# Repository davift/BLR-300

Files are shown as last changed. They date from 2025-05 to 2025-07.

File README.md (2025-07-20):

# BLR-300

Key Card Addon: Binary LED Reader - 300 (BLR-300)

This write-up walks through the process of solving the hardware challenge in the NSEC 2025 CTF.

**NOTE:** This is a beginner-friendly challenge that mostly requires investigating traces and understanding the direction of current flow.

The official source code released by NSEC for the Badge and Dock is available at [NSEC-Badge](https://github.com/nsec/nsec-badge/)

## Overview

The objectives of this challenge are:

- First, fix the existing issues on the provided board so it will properly blink the LEDs.
- Second, decipher the message output by the LEDs to obtain the flag.

**Note:** The board is attached to the badge, which is then connected to a dock available next to the soldering village to output the ciphered code. The badge by itself does not light up anything. The secret message resides on the dock. I saw one participant sniffing the pins on the badge to capture the ciphered message without fixing the board. While extremely clever, the board will reveal necessary facts about some of the pins.

Overview

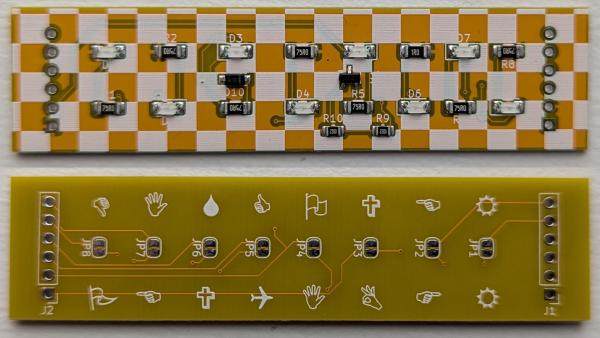
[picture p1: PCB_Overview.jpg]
Overview of the Board


I decided to write this guide because, after talking with participants of the competition, most were not familiar enough with the challenge to give it a try.

## Beforehand

A PDF was provided: [BLR-300-Reference-manual.pdf](https://github.com/davift/BLR-300/blob/main/BLR-300-Reference-manual.pdf), which is a guide/datasheet and also provides clues about what to look for.

Read it carefully before making any modifications to the board. Make notes of the tips and clues in that document to explore.

## Pinout and Schematics

Start by drawing a schematic of the circuit. KiCad (a free and open-source application) might help, but just pen and paper can get the job done.

**NOTE:** There is a checkered pattern printed on the board to make following the traces and reverse engineering more difficult.

Datasheet Notes Revealed

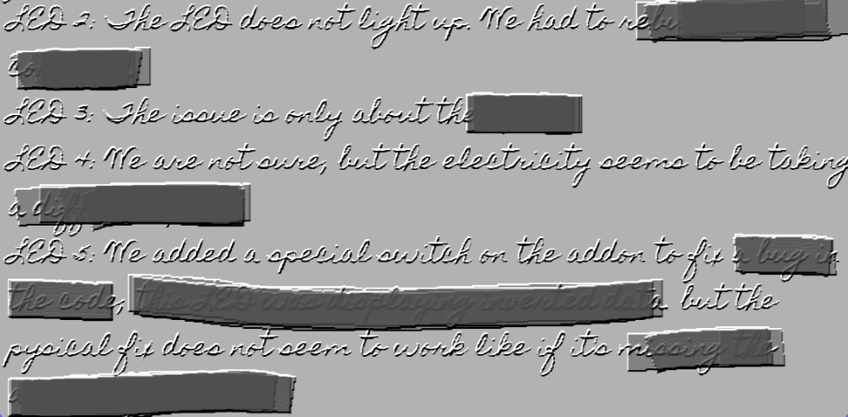
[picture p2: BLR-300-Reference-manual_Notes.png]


Datasheet Pinout Table

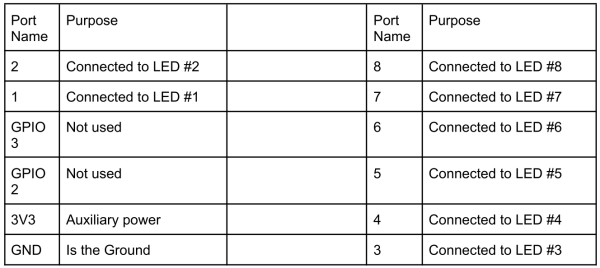
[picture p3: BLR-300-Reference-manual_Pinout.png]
Pinout Table


Pinout (see high resolution here: [PCB Front](https://github.com/davift/BLR-300/blob/main/PCB_Front_Big.jpg) and [PCB Back](https://github.com/davift/BLR-300/blob/main/PCB_Back_Big.jpg)).

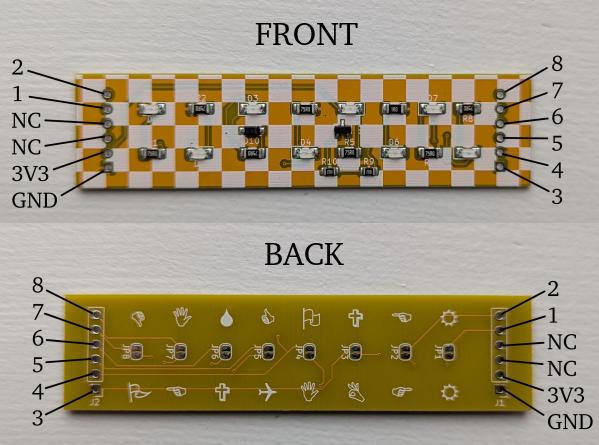
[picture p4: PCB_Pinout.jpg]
Board Pinout


Schematics (see high resolution here: [PCB Schematics](https://github.com/davift/BLR-300/blob/main/PCB_Schematics_Big.png)).

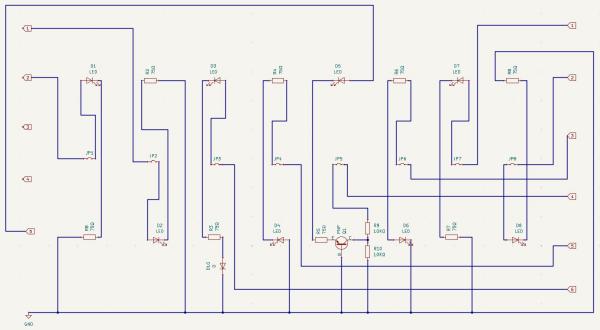
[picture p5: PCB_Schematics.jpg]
Schematics


Basic steps:

- Visually inspect the board and all its features/components.
  - Identify the 8 LEDs.
  - Identify the resistors connected to each LED.
  - Identify any other components and what they relate to.
  - Use a flashlight to shine through the board. This allows you to see behind the printed obfuscation pattern.

See through paint with backlight (see high resolution [here](https://github.com/davift/BLR-300/blob/main/PCB_Backlight_Big.jpg)).

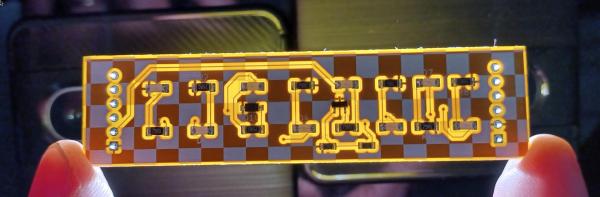
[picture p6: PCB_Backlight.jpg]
PCB Backlight


- Use a multimeter to:
  - Test continuity between all 12 pins of the board (some might be shorted).
  - Follow each trace on the board to test for connectivity (some might be broken).
  - Test LEDs and other diodes for polarity (some might be inverted).
  - Test the resistors (some might not be appropriately sized).
  - Cross-reference the pinout table from the datasheet with the LEDs (some might be swapped).

By performing the inspections above, most, if not all, issues can be identified.

## Issues Found

### LED 1

Testing the LED orientation with a multimeter will reveal it is incorrect.

It is necessary to desolder and solder it back. This process frequently destroys the LED because of the heat. If necessary, ask for another RED SMD LED from one of the organizers.

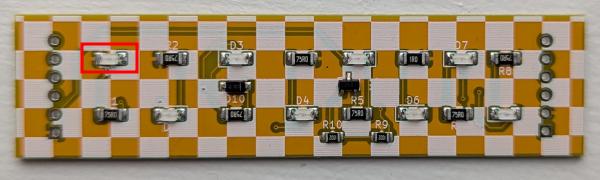
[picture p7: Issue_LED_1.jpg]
Issues on LED 1


### LED 2

There is no connectivity between the header pin and the LED. A visual inspection may not reveal this issue because of the printed obfuscation pattern. Use the multimeter to check continuity.

It is easy to fix with an external wire to make the route.

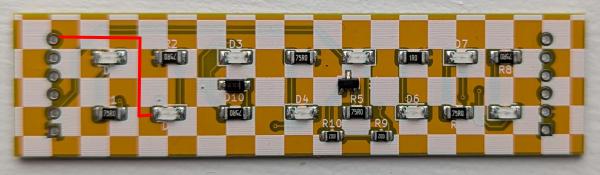
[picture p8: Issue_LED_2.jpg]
Issues on LED 2


### LED 3

Visually, it is not possible to see the polarity of the diode in series with this LED. Use the multimeter to check continuity through the components.

The highlighted diode is not necessary and can be bypassed or have its orientation inverted.

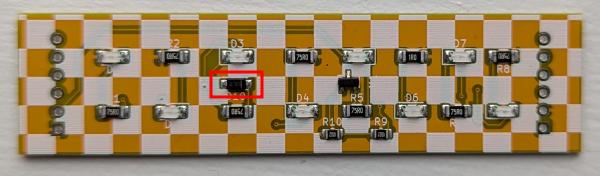
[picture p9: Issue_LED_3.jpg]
Issues on LED 3


### LED 4

This LED appears to malfunction, but the circuit is shorted in multiple locations.

On the back, there is an odd trace to a hole right next to ground on the other side. Cut it with a utility knife or any sharp metal tool.

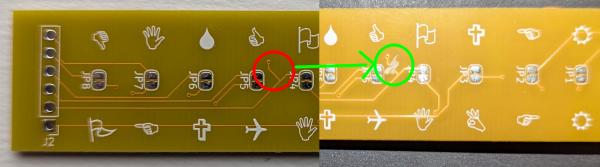
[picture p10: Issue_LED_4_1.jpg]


On the front, there are two other shorts right at the header pin. If the header is already soldered, it might be a bit trickier to cut them.

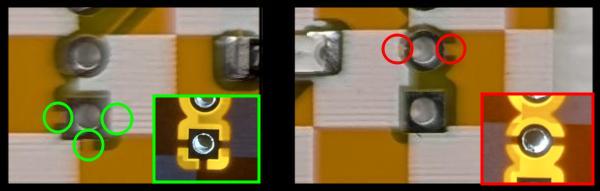
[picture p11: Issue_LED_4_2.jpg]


### LED 5

This was the trickiest issue in this challenge because it takes time to analyze what this extra circuit is doing: a PNP transistor with two 10K ohm resistors.

There is no issue with the transistor, after all. But the circuit that connects pin 3V3 to the LED does not work and needs to be re-routed.

I did not find any purpose for resistors 9 and 10, so I shorted 9 and removed 10. Maybe it was not necessary.

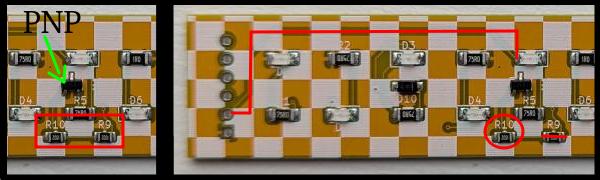
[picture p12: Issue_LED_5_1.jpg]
Issues on LED 5


### LED 6

The manual has the note: "The LED has a tendency to die easily if lighted up for a long time." This comment implies that the resistor that protects the LED is too low or nonexistent.

A visual inspection might reveal that, while all the other LEDs have a 75-ohm resistor, this LED has a 1-ohm resistor. Just ask the challenge organizers for a replacement resistor.

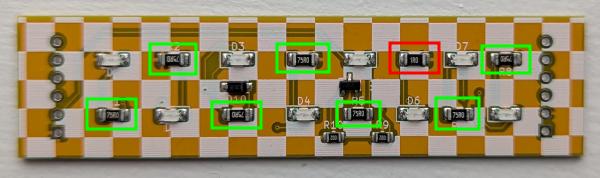
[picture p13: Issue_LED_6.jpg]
Issues on LED 6


### LED 7 and LED 8

These two work out of the box, which makes it easy to overlook that they are swapped. This issue will cause the encoded/ciphered message to be incorrect.

Open the bridges on the back and reroute the circuits, swapping the pins using any piece of wire.

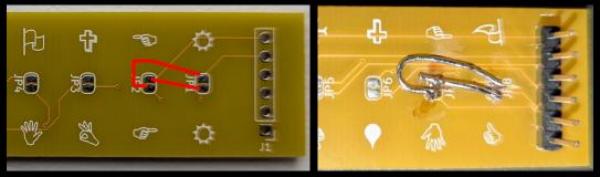
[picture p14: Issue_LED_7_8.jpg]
Issues on LED 7 and 8


## Issues Fixed

This is how the changes look after all fixes have been applied.

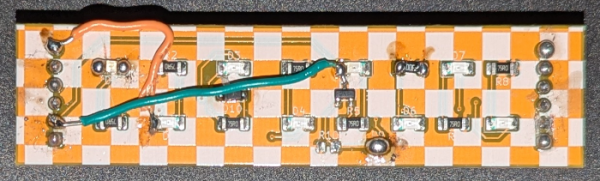
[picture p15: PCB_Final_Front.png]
PCB Final Front


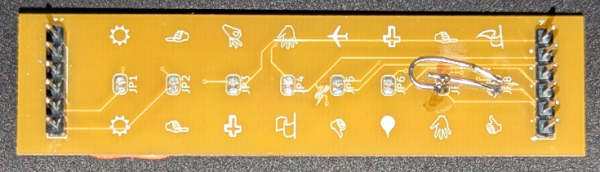
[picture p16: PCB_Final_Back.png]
PCB Final Back


At this point, the PCB can be connected to the badge and attached to the dock provided by the organizers of the challenge to capture the ciphered code.

## Encoded system

[![Message Captured]](https://www.youtube.com/shorts/3g_Ai0capvw)

From the video we got the following byte sequence.

Note: LEDs 7 and 8 were still inverted at the time of the recording.

```
00001010
00100111
11011000
11110101
00001010
11110101
00001010
10001111
00001101
00000110
10000111
00010001
00101111
00011100
00110010
10110110
10100110
10010110
00011100
10110010
00010101
00001110
00111111
00110010
10010110
00110010
10100110
00000101
00001110
00011111
10011101
10110010
10110110
00010010
11110101
00001010
11110101
00001010
11011010
11011000
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
...
```

The comment in the datasheet "Expected Communication Pattern on a non-rewired addon: 11110101 00001010 ..." indicates the begining of the message. We have a match!

There are two keys described in the datasheet as CLIENT DEFAULT KEY and SCRAMBLED KEY.

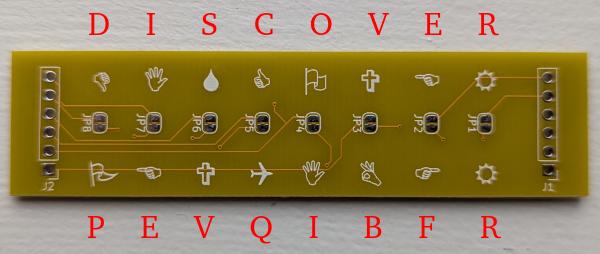
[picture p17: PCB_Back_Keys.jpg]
PCB Final Back


There is an old Windows font called Wingdings that contains the same symbols printed on the back of the board. Those keys were decoded with the chart below.

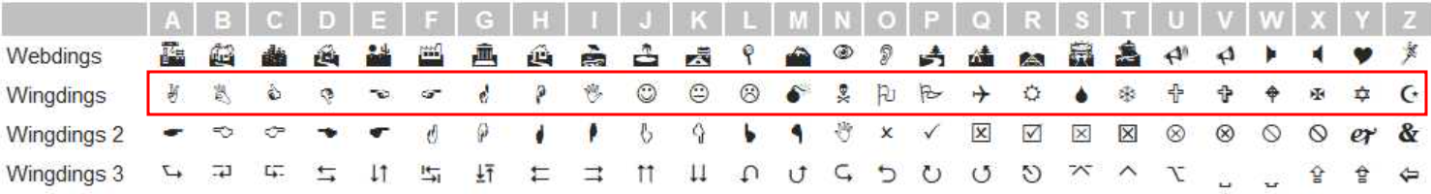
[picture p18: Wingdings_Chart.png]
Wingdings Chart


(to be continued)

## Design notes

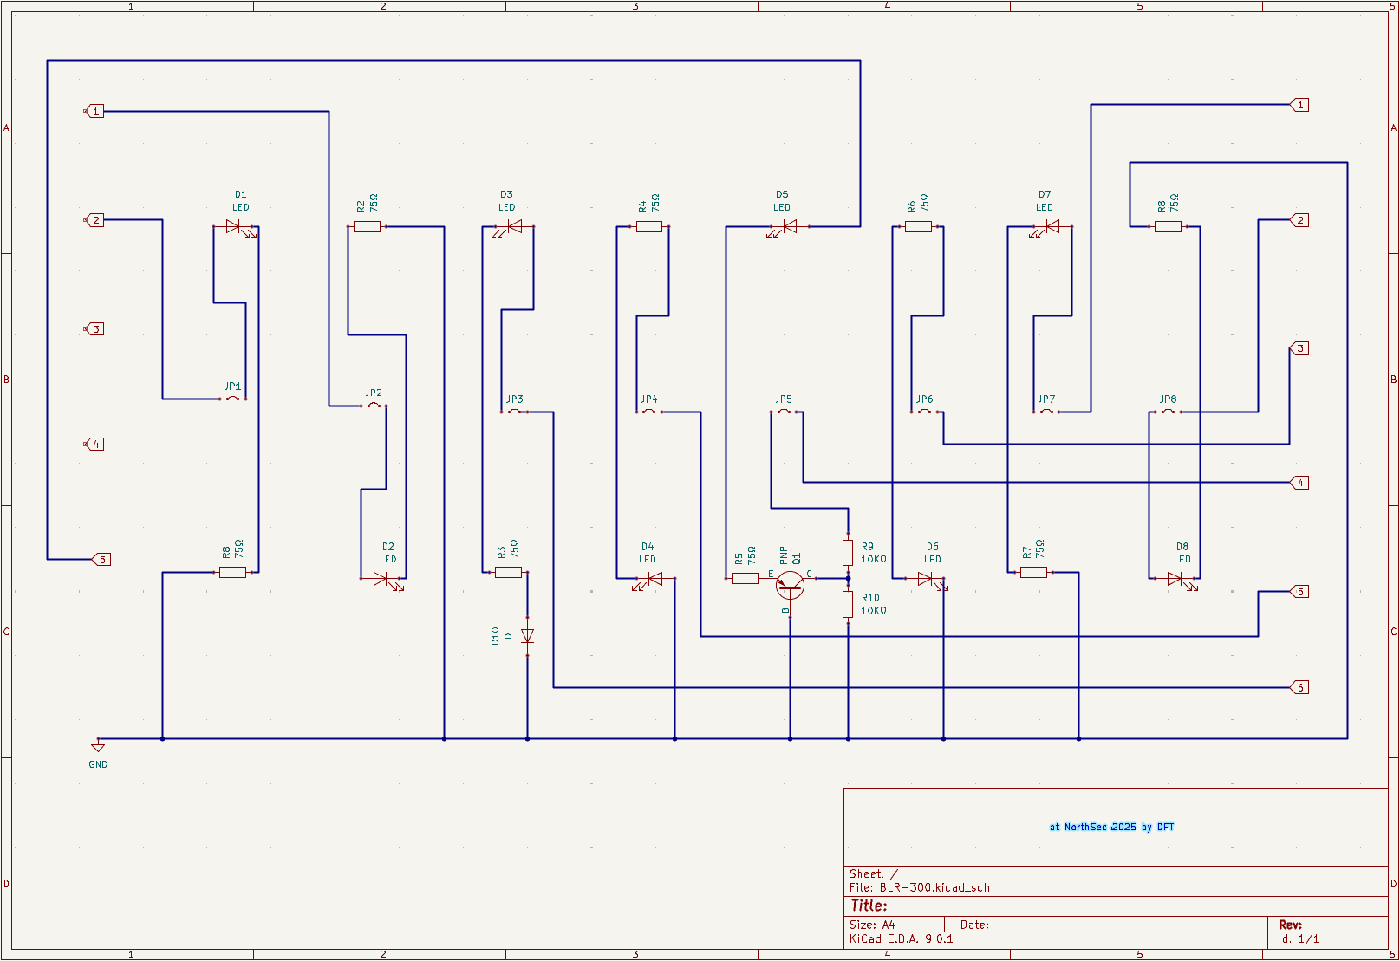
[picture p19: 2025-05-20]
PCB_Schematics_Big.png

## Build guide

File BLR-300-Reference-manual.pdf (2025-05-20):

# Ke Car Addo: Binar LED Reader - 300 (BLR-300)

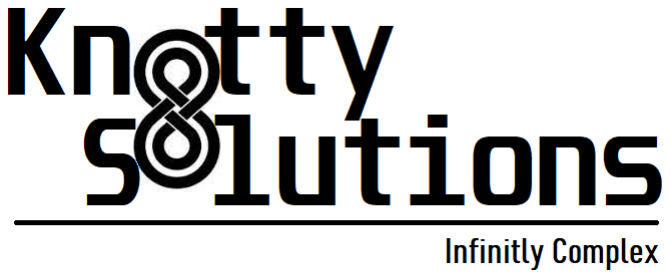
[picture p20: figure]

## Reference Manual

Beta version 0.7.9 (Not for public distribution)
FLAG-ITS-RTFM-TIME!!

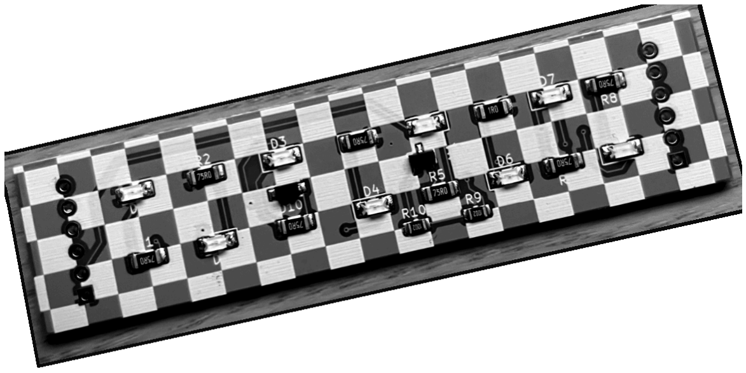
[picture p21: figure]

# OVERVIEW

AT Knotty Solutions we create complex products. We firmly believe that by using more complex ways to build our solutions we improve the security of our products. This add-on represents the hard work we have put in order to reach a nice peak in security.

For our main product; the key card reader system, we created a special Addon, named the BLR-300, that allows our customers to access more information when interacting with the card reader. Through that addon, we are using an advanced communication system based on 8 LEDs designed to communicate with binary. This makes the debugging process much more efficient when using the card reader system.

Dev notes (TODO remove for final release):

# ADDON DISTRIBUTION AND INSTALLATION

Since the BLR-300 is not designed for public usage, and should not be distributed to the public, in order to reduce the cost, the initial package comes in separate pieces. You will need to assemble your own addon.

Note: Make sure you carefully assemble connection legs; they need to have a correct solder and correctly aligned for an easier insertion.

Note: For the installation of the addon on the key card, make sure you use this orientation:

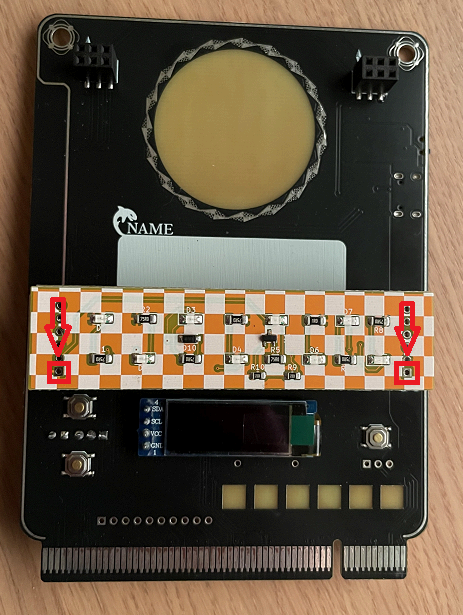
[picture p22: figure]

Dev notes (TODO remove for final release):

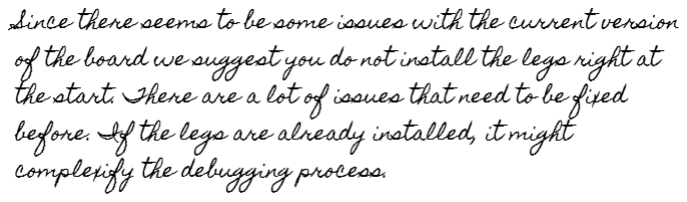
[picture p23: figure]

# ADDON MAINTENANCE

If you are required to do some maintenance on the BLR-300, know this will void your warranty. This means in order to keep our technology super secret, we do not provide in-depth information on the construction of the add-on; so no BOM, or schematic. Which means you will have to re-order the add-on from us via your sales representative.

To further repel anyone that would even try to do reverse engineering on our product we even made the reading of the board harder with a special pattern printed on it to protect the BLR-300 from reverse engineering!

Dev notes (TODO remove for final release):

# Architecture Overview

The addon uses 8 LEDs to communicate. To have an efficient communication protocol, each LEDs is connected to its own port. Here is a small Communication PORT reference grid.

Port Name | Purpose | Port Name | Purpose
2 | Connected to LED #2 | 8 | Connected to LED #8
1 | Connected to LED #1 | 7 | Connected to LED #7
GPIO 3 | Not used | 6 | Connected to LED #6
GPIO 2 | Not used | 5 | Connected to LED #5
3V3 | Auxiliary power | 4 | Connected to LED #4
GND | Is the Ground | 3 | Connected to LED #3

Dev notes (TODO remove for final release):

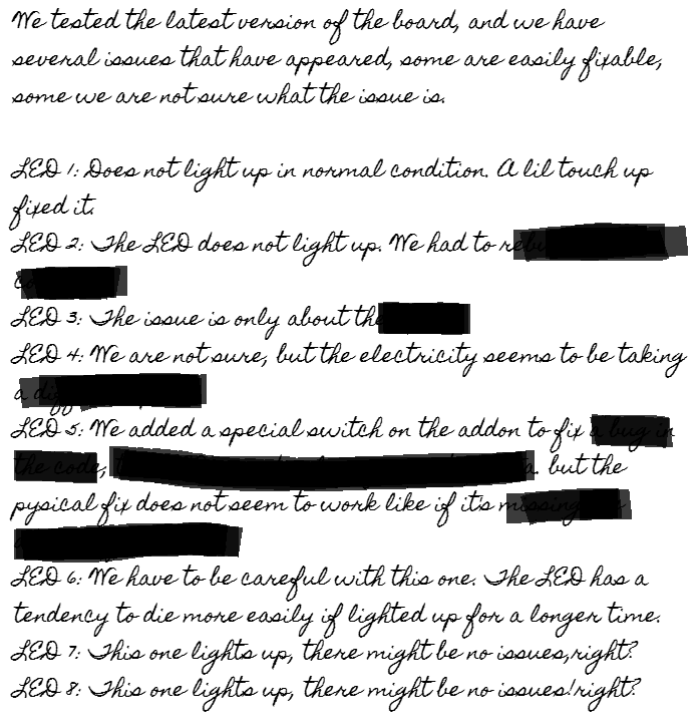
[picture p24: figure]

# Communication Protocol

The Addon will communicate with the LEDs in a specific pattern. It will output messages in a binary format using all 8 LEDs. So it's very important that all the LEDs are functional. In order to make sure you get all the messages we have a special communication header and footer that indicates you everything is functional like it should.

After connecting the augmented badge with an add-on to a station, the LEDs will start displaying data.

IF the addon has been rewired to apply the scrambled key correctly, the following will be displayed:
Communication Header Pattern:

All LEDs ON
All LEDs OFF
All LEDs ON
All LEDs OFF
Bottom LEDS ON Only
Top LEDS ON Only
All LEDs ON
All LEDs OFF
All LEDs ON
All LEDs OFF

Communication Data:

Normal Binary Data

Communication Footer Pattern:

All LEDs ON
All LEDs OFF
All LEDs ON
All LEDs OFF
Top LEDS ON Only
Bottom LEDS ON Only
All LEDs ON
All LEDs OFF
All LEDs ON
All LEDs OFF

Dev notes (TODO remove for final release):

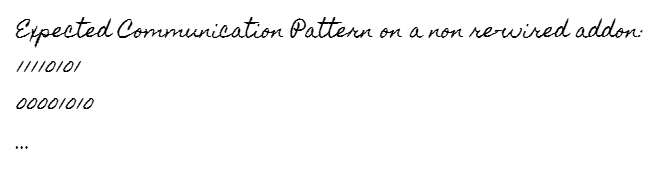
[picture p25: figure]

# Encoded system

To further improve the security of our addon, we personalize the addon connection for each client. We create a unique key that links the addon to the stations provided so they don't work at our other client’s stations. In other words the stations provided use the encoded scrambled key and the Addon must be rewired to match your stations.

By default the addon is using the default wiring to use the default non-scrambled key.

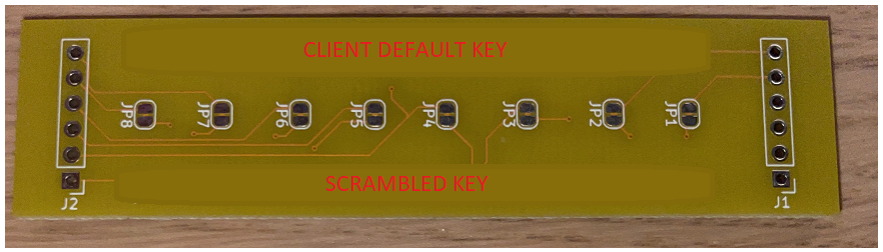
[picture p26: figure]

To make the addon work with your stations, first you must cut the default connection and then rewire the connection to match the scrambled key.

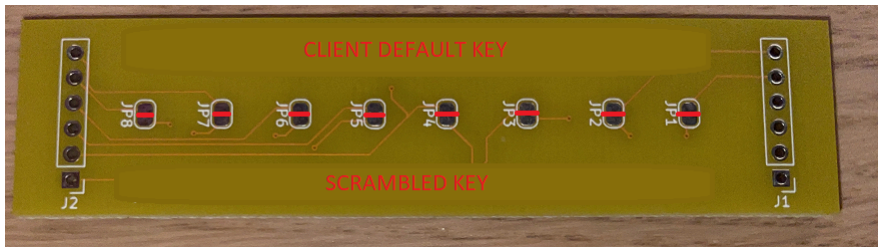
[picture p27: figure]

Note: The printed version of the scrambled key also has been passed through a substitution cipher to protect it.

Extra notes

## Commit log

2025-05-20 Initial commit.
    [BLR-300.kicad_sch]
2025-11-09 backing up draft files
    [BLR-300.kicad_pcb]
